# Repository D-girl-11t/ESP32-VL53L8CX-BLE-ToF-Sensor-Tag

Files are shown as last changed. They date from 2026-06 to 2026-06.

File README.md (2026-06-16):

# ESP32 BLE Time-of-Flight Sensor Tag




This project is a battery-powered BLE sensor tag built around an ESP32 and a VL53L8CX Time-of-Flight (ToF) sensor. The system continuously captures distance measurements at a fixed rate, stores recent readings in memory, and streams data over Bluetooth Low Energy whenever a client connects.

The goal of this project was to build a complete embedded system, covering hardware design, power management, real-time firmware, BLE communication, and data buffering.

---

## What It Does

* Measures distance using the VL53L8CX ToF sensor
* Samples data at a fixed rate (20 Hz by default)
* Stores the most recent measurements in a ring buffer
* Streams live or buffered data over BLE
* Continues sampling even when BLE is disconnected
* Supports battery-powered operation with USB charging
* Places the sensor into a low-power state when sampling is disabled

---

## Hardware Overview

The hardware is based on an ESP32-C3 module connected to a VL53L8CX ToF sensor over I²C.

Power comes from either:

* A single-cell LiPo battery
* USB power during charging

A BQ-series charger with power-path management handles charging and automatically switches between USB and battery operation.

For debugging and bring-up, the board includes:

* Programming header
* Test points for VBAT, VSYS, 3V3, and GND
* Charger status monitoring points
* Clearly labeled silkscreen

### Sensor Interface

The VL53L8CX is connected over I²C and uses two additional GPIO signals:

* **INT** – Sensor interrupt output
* **LPn** – Sensor enable/low-power control

The LPn pin is used to enable or disable the sensor from firmware:

* LPn HIGH → Sensor active
* LPn LOW → Sensor in low-power mode

---

## Firmware Overview

To keep sensor acquisition independent from communication, the application is split into two tasks:

### Sensor Task

Responsible for:

* Reading data from the VL53L8CX
* Maintaining a fixed sampling rate
* Writing measurements into the ring buffer
* Tracking buffer overflows

### BLE Task

Responsible for:

* BLE advertising and connections
* Sending notifications
* Handling control commands
* Streaming buffered data

Since both tasks access the same buffer, a FreeRTOS mutex is used to protect shared data.

---

## Sampling Strategy

The default sampling rate is 20 Hz, which corresponds to one measurement every 50 ms.

The sampling task runs on a fixed schedule and is intentionally kept independent of BLE activity. This ensures that sensor timing remains consistent even when notifications are being transmitted.

One practical optimization is minimizing debug print statements. Excessive UART logging can introduce delays that affect timing accuracy, especially when working with millisecond-level scheduling.

If a sensor read ever takes longer than the allocated sampling window, that sample is dropped rather than delaying future measurements. Under normal operating conditions, this is not expected to occur with the selected VL53L8CX configuration.

---

## Ring Buffer Design

The assignment required storing the last **N seconds** of sensor data.

By default:

* Sampling rate = 20 Hz
* N = 10 seconds

This results in:

* 20 samples per second
* 200 samples stored in memory

For an 8×8 VL53L8CX ranging frame:

* 64 distance values per sample
* 4 bytes per value
* 256 bytes per frame

Memory usage is approximately:

* 5 KB per second of buffered data
* 50 KB for a 10-second history

The values of **N** and buffer size are currently fixed constants for simplicity but can easily be made configurable.

### Buffer Overflow Behavior

When the buffer becomes full, the oldest data is overwritten.

For this application, retaining the most recent measurements is more useful than preserving older data, so overwrite-on-full was chosen intentionally.

Different applications may require different strategies depending on how critical the data is.

---

## BLE Control Interface

The BLE service exposes two characteristics:

### Data Characteristic

Used for notifications.

When connected, the client receives:

* Live sensor data
* Previously buffered data

### Control Characteristic

Used for configuration and runtime control.

Supported commands:

* `startSampling`
* `stopSampling`
* `startBLE`
* `stopBLE`
* `SetRate:<value>`
* `Clear`

---

## Why Separate Sampling and BLE?

The original assignment mentioned Start and Stop commands, but it was unclear whether those commands should affect the sensor, BLE communication, or both.

To make the behavior explicit, the implementation separates them into two independent controls.

### Sampling Control

* `startSampling`
* `stopSampling`

These commands control whether the sensor is actively acquiring measurements.

### BLE Control

* `startBLE`
* `stopBLE`

These commands control whether data is transmitted to connected BLE clients.

This approach makes system behavior easier to understand and provides more flexibility during testing.

---

## Operating Modes

### Sampling Enabled, BLE Disabled

The sensor continues collecting measurements and storing them in the ring buffer.

If the buffer fills up, the oldest entries are overwritten.

### Sampling Disabled

The sensor is disabled through the LPn pin and enters a low-power state.

### Sampling Enabled, BLE Enabled

The system continues collecting measurements while simultaneously transmitting data over BLE.

When BLE is enabled, buffered measurements are sent first before transitioning to live streaming.

### BLE Disabled During Operation

Sensor acquisition continues normally, but measurements are only stored locally.

### Clear Command

Removes all buffered measurements and resets buffer tracking information.

---

## Power Management

The VL53L8CX supports a low-power mode through the LPn pin, which is used whenever sampling is stopped.

ESP32 light sleep and deep sleep were also evaluated. However, entering sleep causes BLE connections to disconnect, so sleep modes are only practical when both sensor acquisition and BLE communication are inactive.

Because of this, the system remains awake whenever BLE functionality is required.

---

## Testing

BLE functionality was tested using nRF Connect.




The following scenarios were verified:

# Sampling with BLE disabled



# StopSampling and no BLE



# Sampling with BLE enabled




# Stopping and restarting sensor acquisition


# BufferSAMPLING RATE 


# Clearing buffered data



The observed behavior matched the intended design in all test cases.

---

## References

VL53L8CX Driver Library:

[https://github.com/stm32duino/VL53L8CX](https://github.com/stm32duino/VL53L8CX)

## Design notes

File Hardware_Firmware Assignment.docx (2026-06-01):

Dhana Laxmi Sirigireddy | Design of ESP32 + VL53L8CX BLE sensor system

Assignment

Design a small ESP32 + ToF BLE sensor tag where:

System

- MCU: ESP32 (ESP32-C3 or ESP32-S3 module)
- Sensor: VL53L8CX ToF over I2C (LPn + INT connected to GPIO)
- Power: 1-cell LiPo + BQ-series charger with power-path
- Comms: BLE (stream when connected, buffer when not)

Hardware task (PCB in KiCad/Altium)

- LiPo JST + USB input for charging
- BQ charger configured (charge current/termination) + documented USB vs battery behavior
- 3.3V rail sized for ESP32 peaks, proper decoupling
- ToF I2C integration (pullups/level shifting if needed), clean routing
- Bring-up features: test points (VBAT/VSYS/3V3/GND + charger status), programming header, clear silkscreen

Firmware task (ESP-IDF + FreeRTOS)

- Fixed-rate sampling (e.g., 20 Hz) independent of BLE
- Ring buffer stores last N seconds; track drops/overflows
- BLE GATT service:
  - Notify “Data” characteristic
  - Write “Control” characteristic (start/stop, set rate, clear buffer)
- When BLE connects: stream latest (or buffered) data without blocking sampling
- When sampling stops: put ToF in low power via LPn (optional light sleep)

Deliverables

- PCB project + 1–2 page design note
- ESP-IDF project + README (build/flash + UUIDs + how to test in nRF Connect)

I started by picking the microcontroller for our project and went with the ESP32-C3 WROOM-02.

The C3 is a single-core chip which is great for low-power stuff and simple WiFi/BLE tasks. It runs a bit slower than the ESP32-S3, which actually helps save energy for lightweight applications like ours.

The S3, on the other hand, is dual-core and more powerful, designed for heavier workloads like AI or advanced data processing.

Since our project is mostly about basic wireless communication and keeping power consumption low, the C3 is the better fit.

I didn’t go with the C3 Mini because the WROOM-02 gives us more flash memory and easier integration for the board we’re building.

Component Selection
ESP32-C3-WROOM-02-N4 Espressif Systems - RF Receivers, Transceivers - Distributors, Price Comparison, and Datasheets | Octopart component search (https://octopart.com/part/espressif-systems/ESP32-C3-WROOM-02-N4) (from Component Search Engine )

Datasheet
https://www.mouser.in/datasheet/2/891/Espressif_Systems_04082021_ESP32_C3_WROOM_02-2295851.pdf

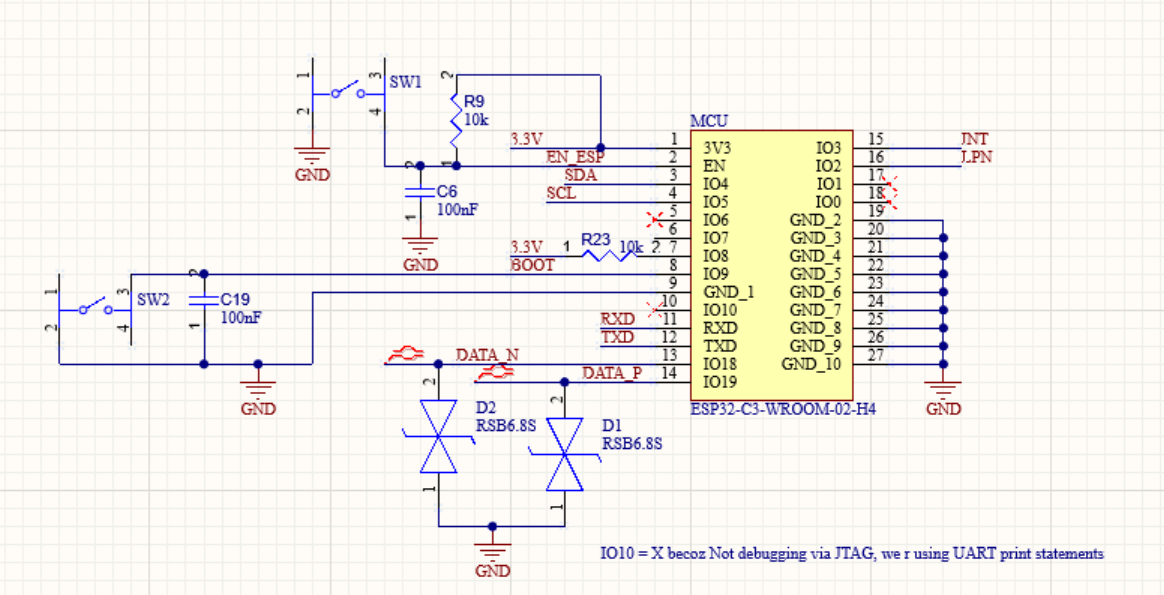
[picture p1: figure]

Next,

Sensor

I initially considered using an off-the-shelf breakout board to make things easier, but I decided to design the whole circuit myself. It turned out to be simpler given the power management path I wanted to implement.

Useful sources
BREAK OUT BOARD SCHEMATIC LINK POLOLU (https://cdn.robotshop.com/media/P/Pol/RB-Pol-1059/pdf/pololu-vl53l8cx-time-of-flight-distance-sensor-8x8-zone-4-m-range-schematics.pdf)

Datasheet
https://www.st.com/resource/en/datasheet/vl53l8cx.pdf

The power-up sequence is detailed on page 11 of the datasheet.
The sensor is connected to ESP via I2C protocol.



To communicate with the ESP, I needed a level shifter because the ESP’s GPIOs are 3.3 V while the sensor pins are 1.8 V. I chose the TXS0108ERGYR (https://www.ti.com/lit/ds/symlink/txs0108e.pdf?ts=1769859893600)for this purpose.
I followed the typical application circuit on page 19 of the datasheet.

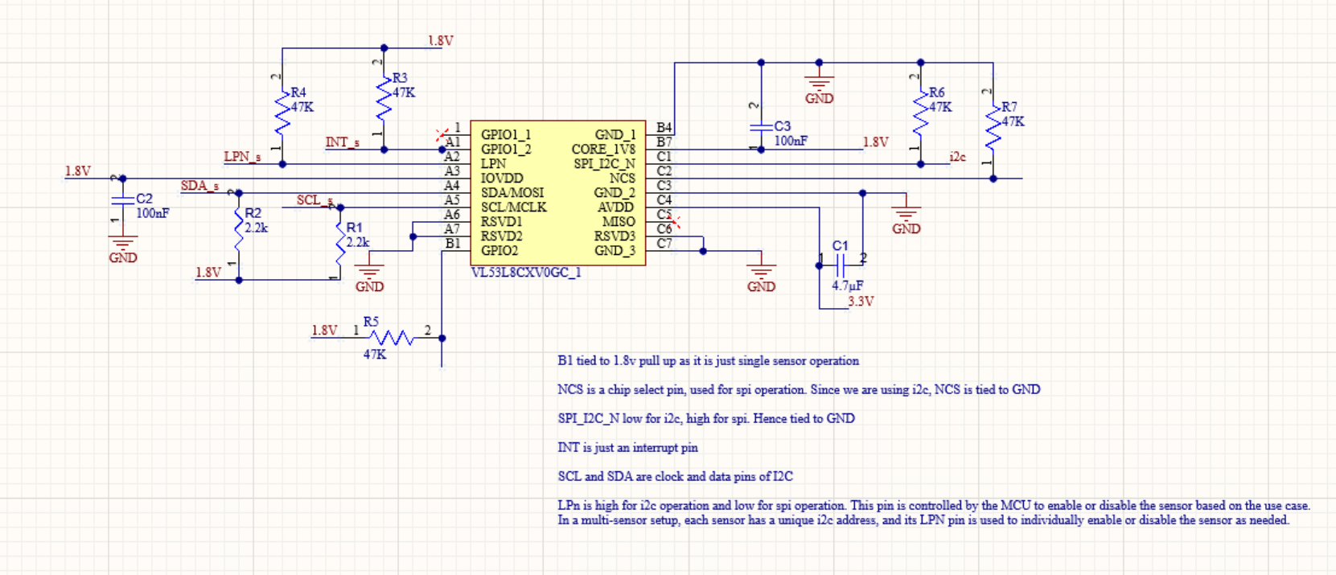
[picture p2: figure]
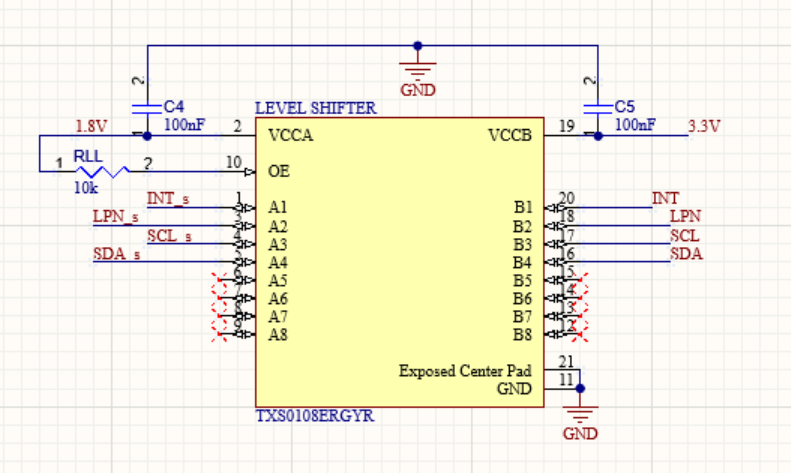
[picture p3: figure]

Flashing and Debugging the ESP32-C3 Board

IO9 is the boot pin on this module.

The ESP32-C3 WROOM-02 has a built-in USB peripheral, which theoretically allows flashing via USB directly by connecting the USB-C data lines to IO18 (D+) and IO19 (D−).

However, this method is not as straightforward as using a standard USB-to-UART bridge.

To make development simple, I implemented a USB-to-UART bridge using the CP2102. This setup:

- Automatically handles boot/reset toggling
- Provides USB debugging, allowing UART print statements to be read directly via USB-C
- Works with standard tools like esptool.py for firmware flashing

For minimal hardware, the board can be flashed manually using the exposed UART pins (TXD, RXD, VCC, GND) along with the BOOT and EN buttons:

1. Hold BOOT (IO9) LOW
2. Press and release EN (RESET)
3. Release BOOT
4. Run

I haven’t used the JTAG feature; those pins are repurposed for I2C, and anyway UART debugging covers all necessary testing and log output.

According to the official ESP-IDF documentation, ESP32 boards typically use a USB-to-UART bridge to expose a virtual COM port for flashing. If auto-download isn’t available, holding BOOT while resetting the board manually enters flash mode. This matches my setup: the CP2102 bridge handles auto-boot, enables convenient UART debugging, and supports standard flashing tools, making development and testing much easier. (ESP-IDF Docs (https://docs.espressif.com/projects/esp-idf/en/stable/esp32/get-started/establish-serial-connection.html))

Schematic source help - https://dl.espressif.com/dl/schematics/SCH_ESP32-C3-DEVKITC-02_V1_1_20210126A.pdf

Powerpath

The board is powered using either a LiPo battery connected via a JST connector or USB-C.

The BQ24072 battery charger IC manages power flow between these sources and the system. (BQ24072 Datasheet (https://www.ti.com/lit/ds/symlink/bq24072t.pdf?ts=1769850111450)). Page 29 has a useful application schematic.

VBUS (USB-C input) When USB-C is connected, it provides power to the BQ24072, which charges the LiPo battery and supplies the system.

VBAT (Battery) Represents the LiPo battery voltage. The battery powers the system whenever USB-C is disconnected or the charger allows.

VSYS (System output from BQ24072) The charger IC outputs VSYS, which automatically selects the higher-priority power source (USB or battery) to provide a stable system voltage.

LDO → 3.3 V rail VSYS is fed into a low-dropout regulator (LDO) to generate a clean 3.3 V supply for the ESP32-C3 and peripherals.


Differential pair impedance
1. Change the rules in diff routine
2. Create impedance profile in layer stack manager
3. Apply in rules

—--

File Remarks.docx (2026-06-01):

Remarks

1. Removing print statement, can save time and makes sure the cycle doesnt break. Since we are dealing with ms [improvement could be done]
2. Sleep mode is disconnecting BLE (both light and deep). Sleep used only when both BLE not asking and sensor not sending
3. Mutex is used to safeguard buffer [FREERTOS] 2 TASKS - SensorTask, BLETask

4. N is default 10, can be changed later
5. And so is buffer size
6. LPN pin operates as per sensor needed to work or not , if yes HIGH, no then low
7. STOP and START are not clear in the assignment, So I used startSampling and stopSampling for sensor to work or not and startBLE and stopBLE for bluetooth to send data or not
8. When startBLE starts, ring buffer values will be sent and buffer slowly empties
9. If Buffer overfilled, overwrites old data as the data here is not critical. Different use case different methods
10. I havent changed the buffer size when the sampling rate changes. I put constant for simplicity

sYSTEM ALSO DEPENDS ON PREVIOUS STATE
Control
1. startSampling
2. stopSampling
3. startBLE
4. stopBLE
5. Setrate:10

6. Clear

For the sensor -
For this assignment lets just do 1 capture per every 50ms. (given fixed sampling rate is 20Hz)

If it takes more than 50ms, lets drop. (it wont usually wont according to the settings or configurations we choose. But if ToF is greater than yeah )

Okay, according to assignment, ring buffer stores last N seconds

1 second = 1000ms = 50 * 20 ms = 50ms * 20 = 20 Samples per second ( if we capture one data value per every 50ms)

Buffer size for N seconds = 20N

8×8 array = 64 values

Each value = 4 bytes = 64 × 4 = 256 bytes per sample

20 samples per second = 256 × 20 = 5120 bytes ( approx 5 KB per second)

For N seconds: Buffer size = 256 × 20 × N = 5120 × N bytes

To read from sensor, use this github page to get real time values from sensor,
https://github.com/stm32duino/VL53L8CX

11. Using nrfConnect, below are the attached pictures

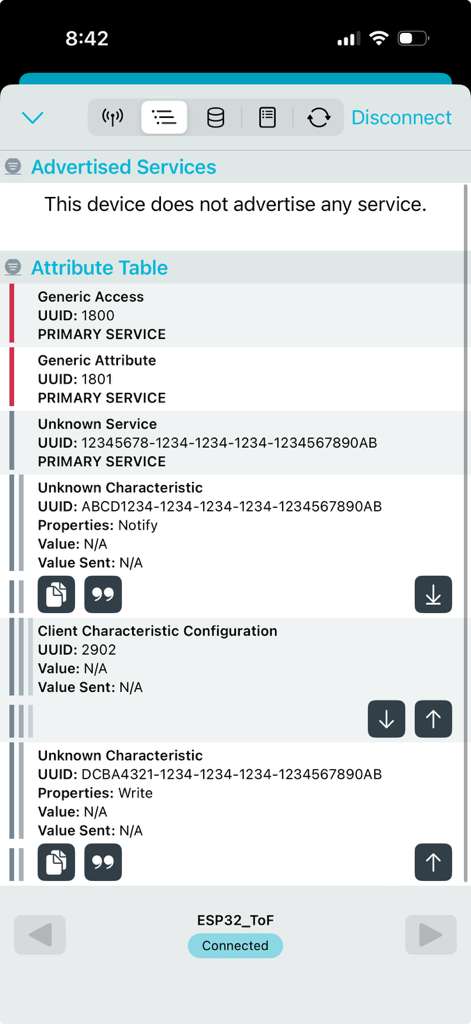
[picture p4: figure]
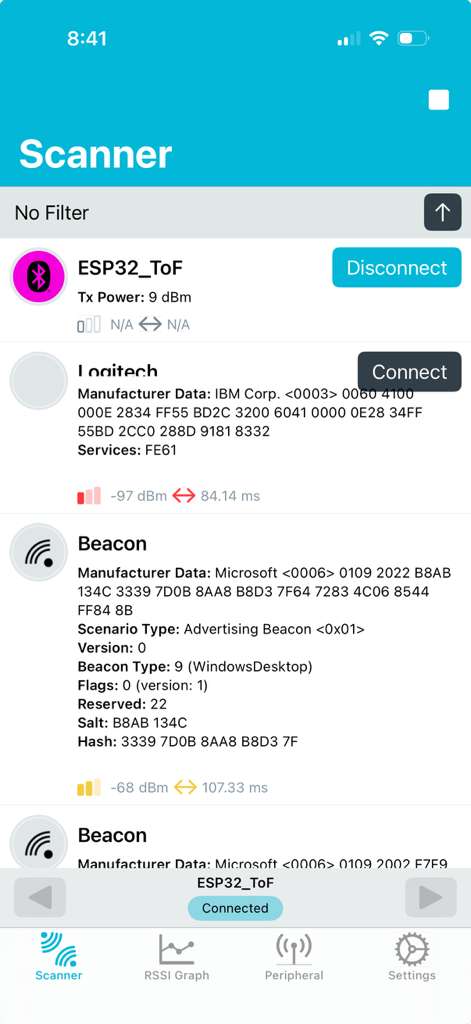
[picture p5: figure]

Normal startSampling = 1 and NO ble . JUST READ AND STORE . OVERFILL -> OVERWRITE

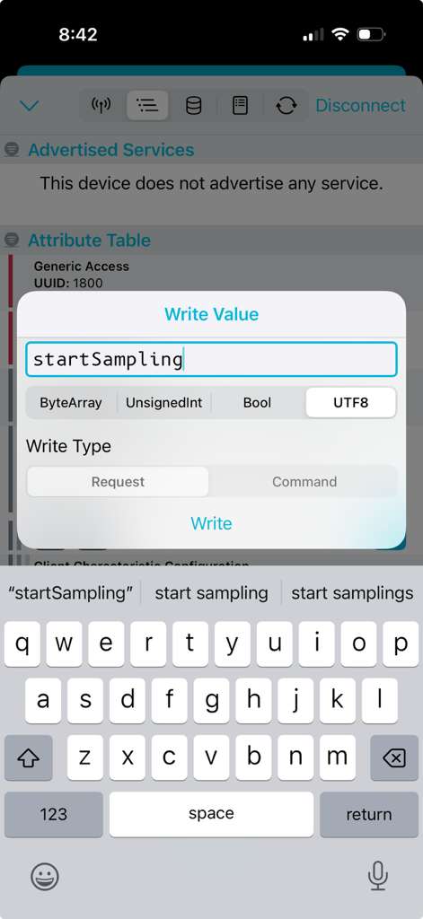
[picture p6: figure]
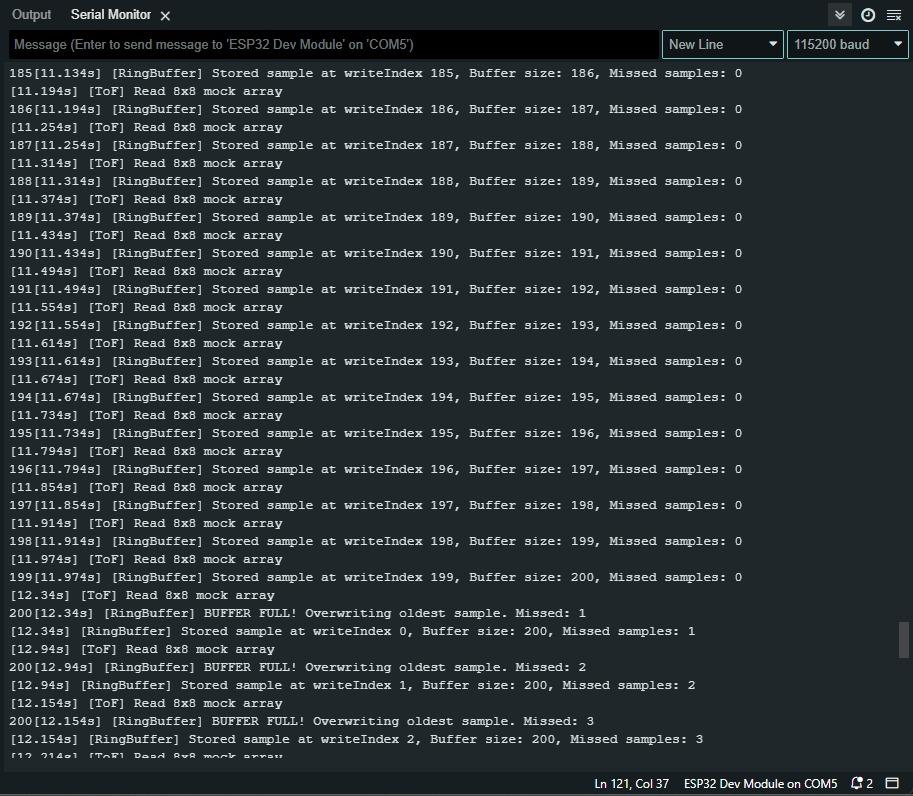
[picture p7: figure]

stopSampling and no BLE

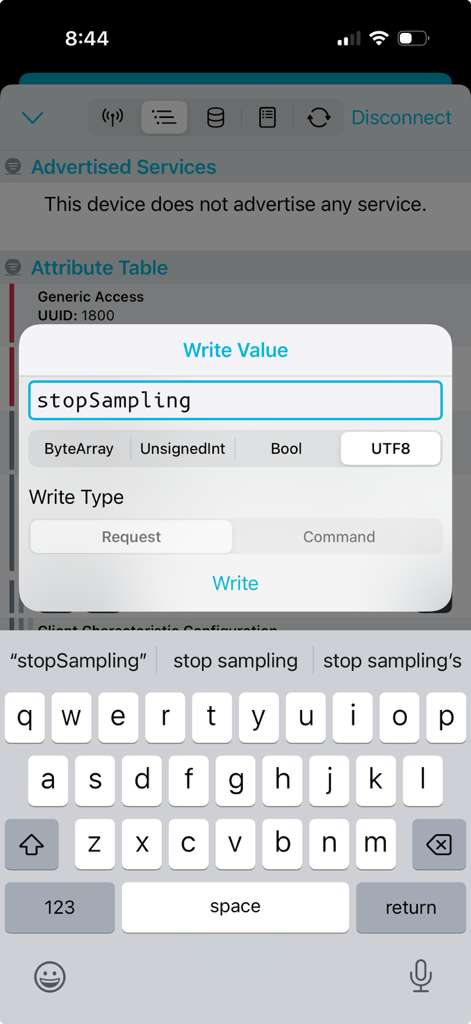
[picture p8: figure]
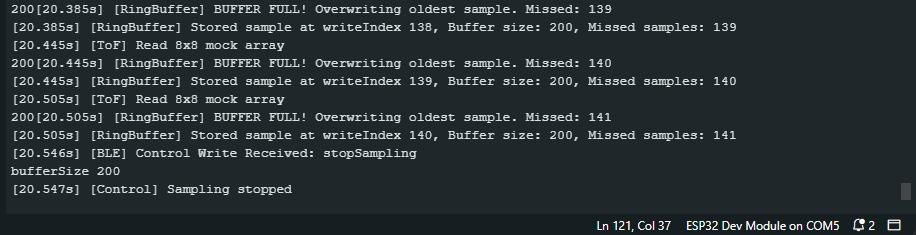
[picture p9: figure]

startBLE AND startSampling

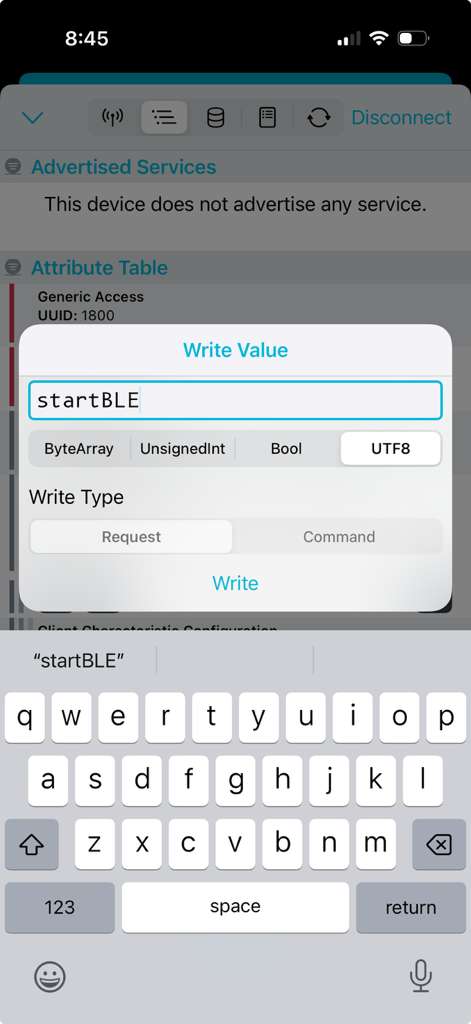
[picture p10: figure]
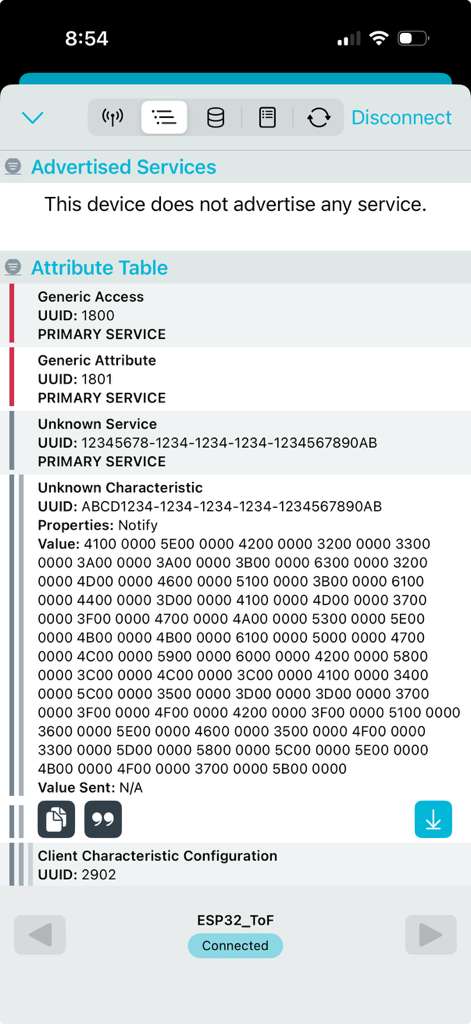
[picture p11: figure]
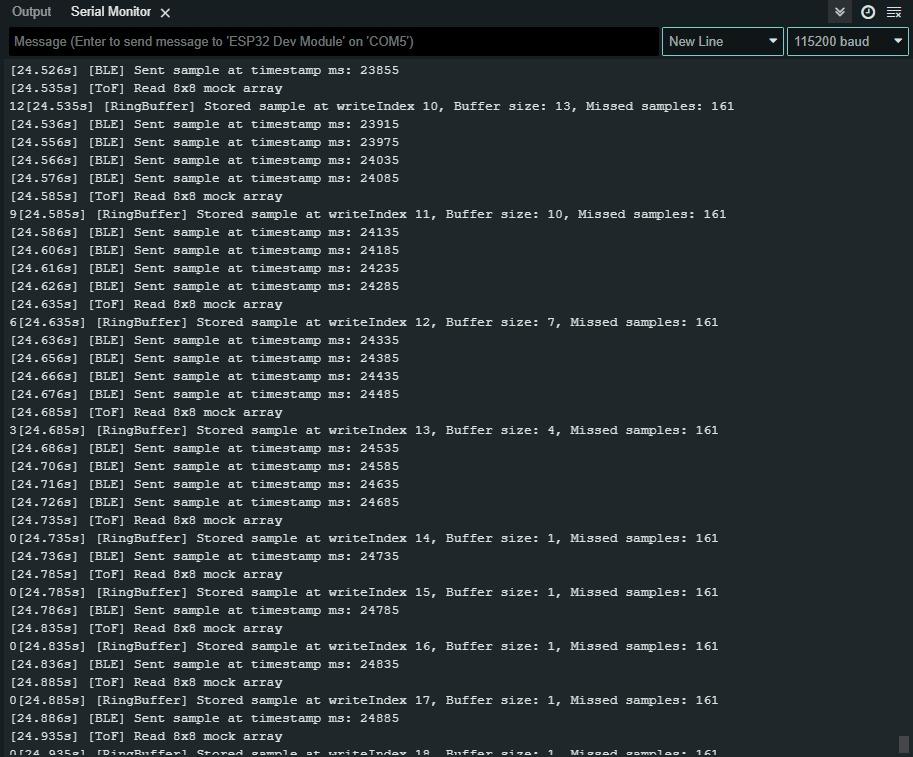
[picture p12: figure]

stopBLE. Back to normal

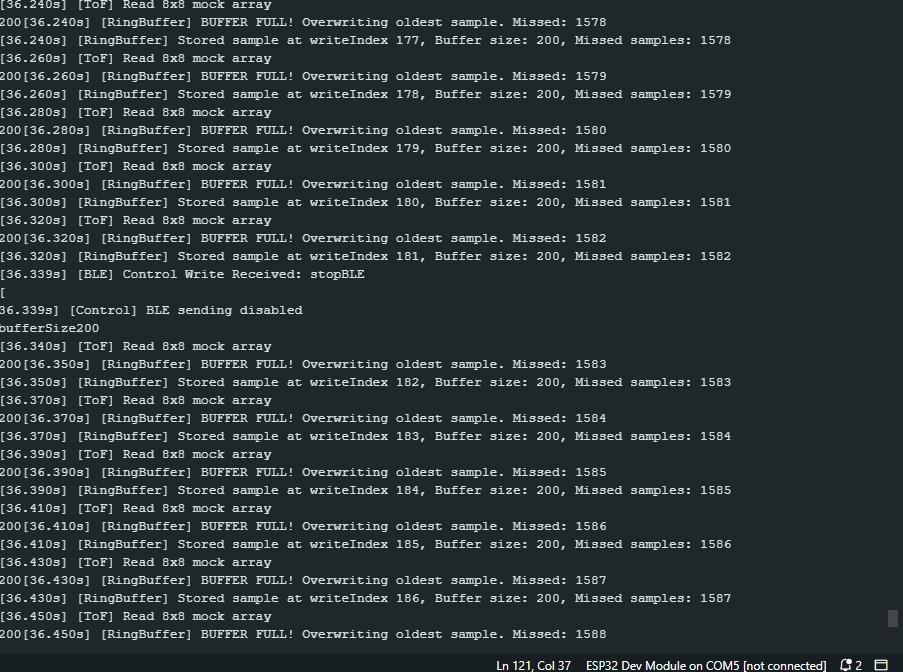
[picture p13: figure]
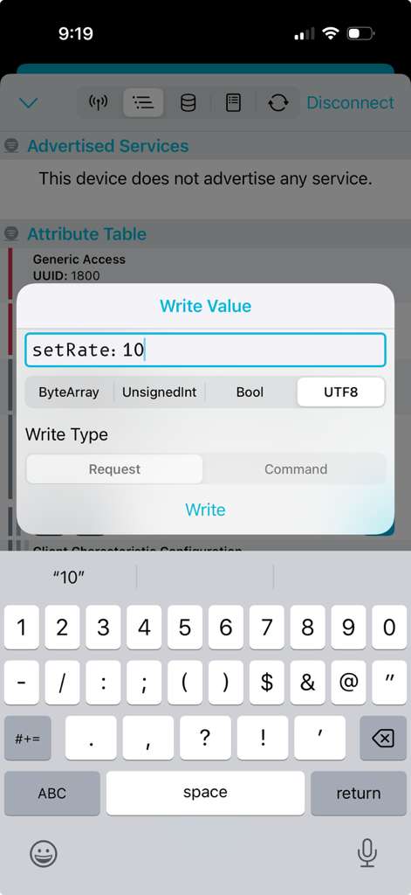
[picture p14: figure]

Clear

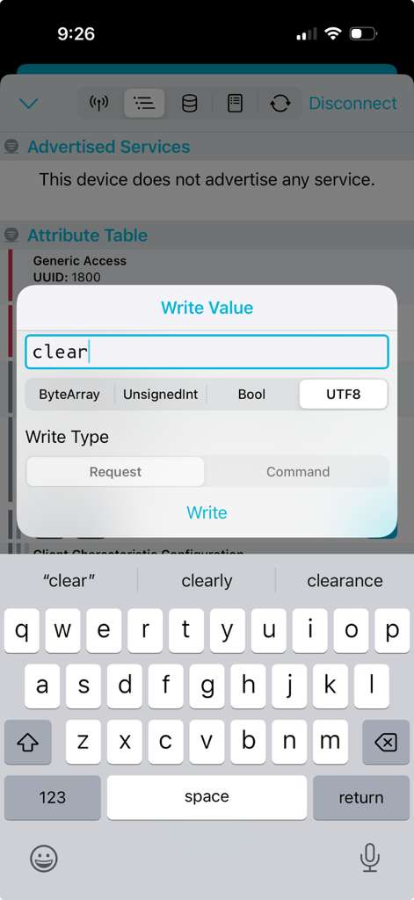
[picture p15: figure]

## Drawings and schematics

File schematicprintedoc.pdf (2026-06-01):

# Power

# ESP32

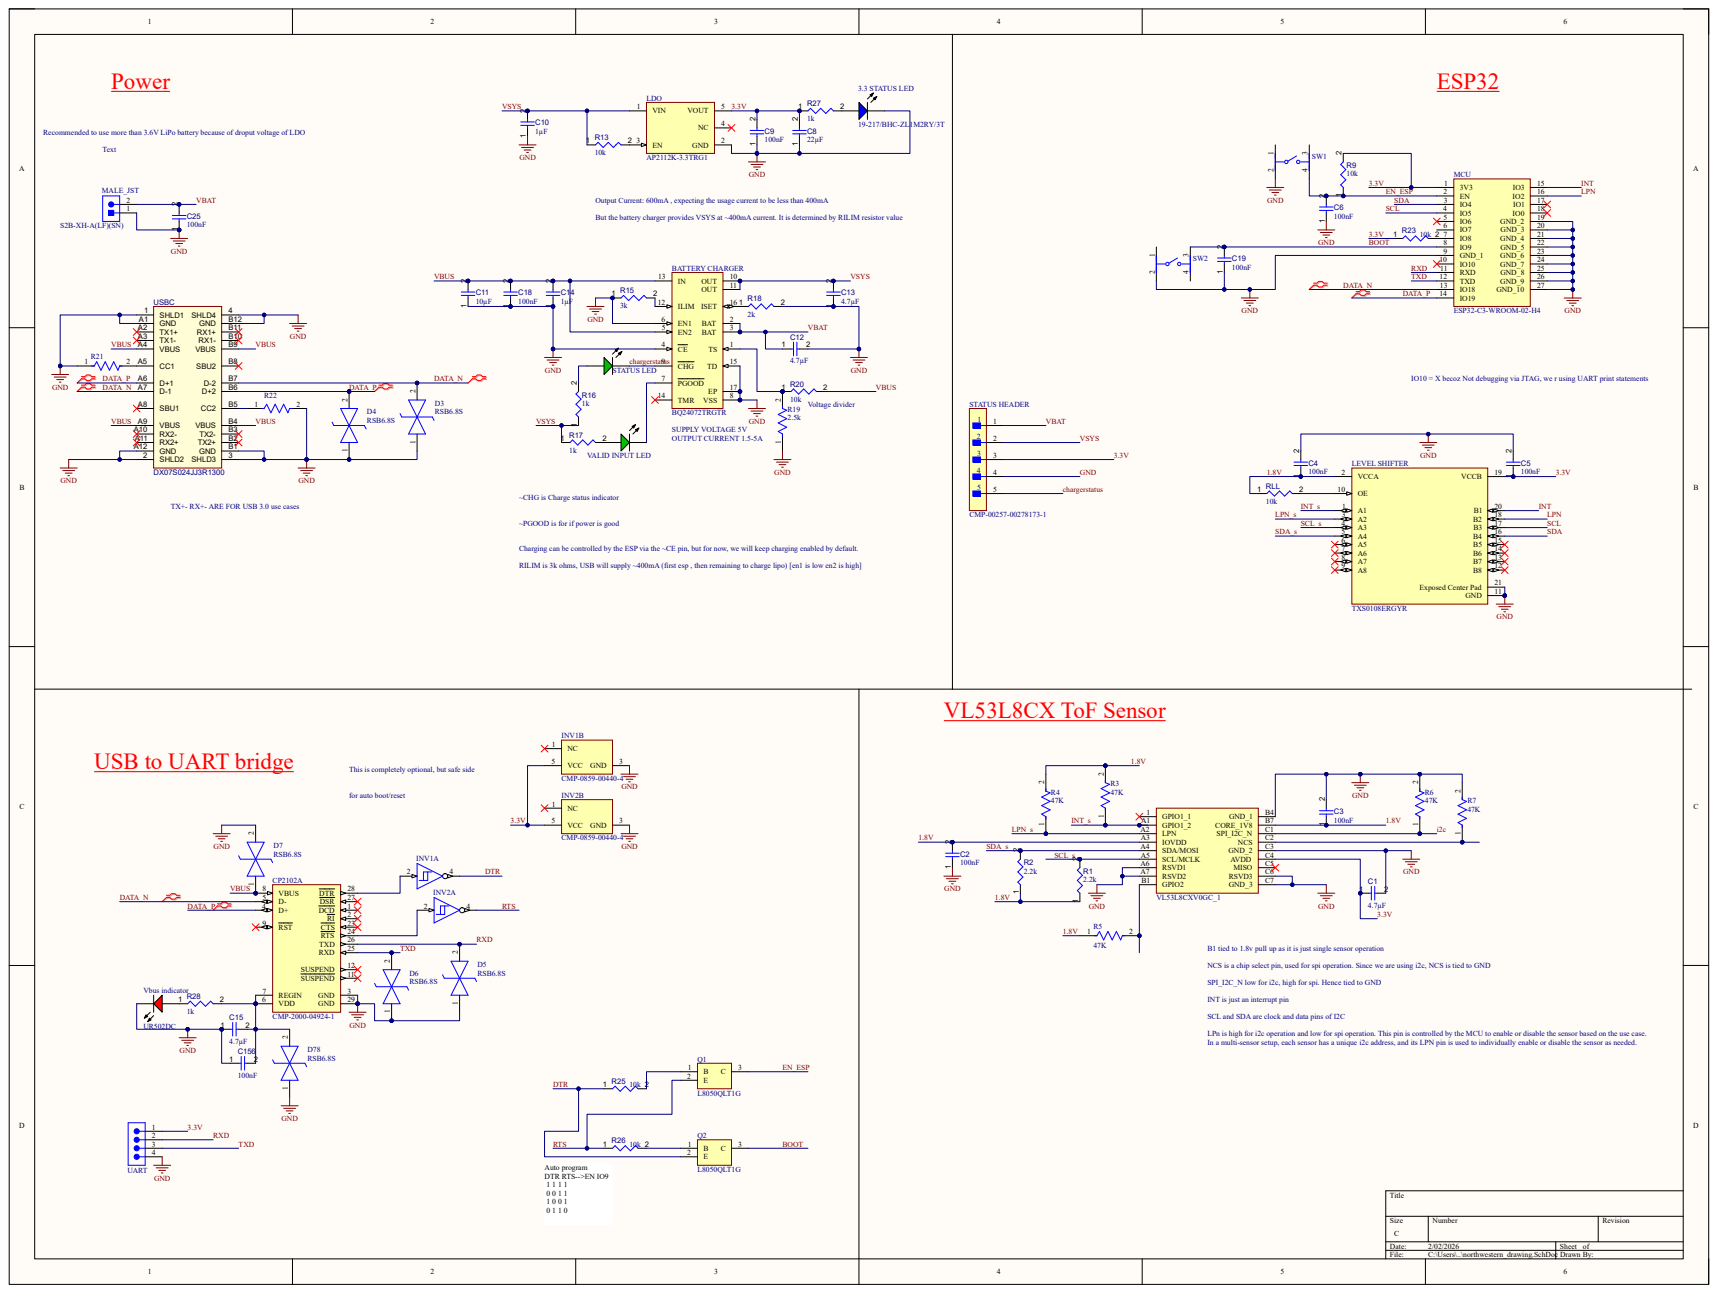
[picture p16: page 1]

Recommended to use more than 3.6V LiPo battery because of droput voltage of LDO

Output Current: 600mA , expecting the usage current to be less than 400mA

But the battery charger provides VSYS at ~400mA current. It is determined by RILIM resistor value

IO10 = X becoz Not debugging via JTAG, we r using UART print statements

~CHG is Charge status indicator

TX+- RX+- ARE FOR USB 3.0 use cases

~PGOOD is for if power is good

Charging can be controlled by the ESP via the ~CE pin, but for now, we will keep charging enabled by default.

RILIM is 3k ohms, USB will supply ~400mA (first esp , then remaining to charge lipo) [en1 is low en2 is high]

for auto boot/reset

B1 tied to 1.8v pull up as it is just single sensor operation

NCS is a chip select pin, used for spi operation. Since we are using i2c, NCS is tied to GND

SPI_I2C_N low for i2c, high for spi. Hence tied to GND

INT is just an interrupt pin

SCL and SDA are clock and data pins of I2C

LPn is high for i2c operation and low for spi operation. This pin is controlled by the MCU to enable or disable the sensor based on the use case.
In a multi-sensor setup, each sensor has a unique i2c address, and its LPN pin is used to individually enable or disable the sensor as needed.

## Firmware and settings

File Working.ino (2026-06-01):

#include <Arduino.h>
#include <BLEDevice.h>
#include <BLEServer.h>
#include <BLEUtils.h>
#include <BLE2902.h>
#include <freertos/semphr.h>
#include "esp_sleep.h" // For light sleep

// -------------------- UUIDs --------------------
#define SERVICE_UUID        "12345678-1234-1234-1234-1234567890ab"
#define DATA_CHAR_UUID      "abcd1234-1234-1234-1234-1234567890ab"
#define CONTROL_CHAR_UUID   "dcba4321-1234-1234-1234-1234567890ab"

// -------------------- Globals --------------------
BLEServer* pServer;
BLECharacteristic* pDataChar;
BLECharacteristic* pControlChar;

bool sampling = true;         // Sensor acquisition flag
bool bleSendEnabled = false;    // BLE notification flag
bool deviceConnected = false;  // BLE connection state

#define WIDTH 8
#define HEIGHT 8
#define SAMPLE_SIZE (WIDTH*HEIGHT*4) // 8x8 array, 4 bytes per value = 256 bytes
#define BUFFER_SECONDS 10             // Buffer stores last N seconds
#define LPN_PIN 15                     // Example LNT / LPn pin

uint16_t effectiveRate = 20; // Samples per second, adjustable via BLE

// Ring buffer parameters
#define MAX_RING_SAMPLES 200  // max slots (can be bigger for large N)
struct RingSample {
    int64_t timestamp_ms;          // Timestamp in ms
    uint8_t data[SAMPLE_SIZE];     // 8x8 ToF data
};
RingSample ringBuffer[MAX_RING_SAMPLES];

uint16_t writeIndex = 0;
uint16_t readIndex  = 0;
uint16_t bufferSize = 0;
uint32_t missedSamples = 0;

SemaphoreHandle_t ringMutex; // Mutex to protect ring buffer

// -------------------- Helper: timestamp string --------------------
String ts() {
    uint32_t t = millis();
    uint32_t s = t / 1000;
    uint32_t ms = t % 1000;
    return String(s) + "." + String(ms) + "s";
}

// -------------------- Mock ToF Reading --------------------
void getToFArray(uint32_t *array) {
    for (int i = 0; i < WIDTH*HEIGHT; i++) {
        array[i] = random(50, 100); // Mock 50-100
    }
    Serial.print("["); Serial.print(ts()); Serial.println("] [ToF] Read 8x8 mock array");
}

// -------------------- BLE Server Callbacks --------------------
class MyServerCallbacks : public BLEServerCallbacks {
    void onConnect(BLEServer* pServer) override {
        deviceConnected = true;
        Serial.print("["); Serial.print(ts()); Serial.println("] [BLE] Device connected!");
    }
    void onDisconnect(BLEServer* pServer) override {
        deviceConnected = false;
        Serial.print("["); Serial.print(ts()); Serial.println("] [BLE] Device disconnected!");
        pServer->getAdvertising()->start(); // Restart advertising
        Serial.print("["); Serial.print(ts()); Serial.println("] [BLE] Restarted advertising...");
    }
};

// -------------------- BLE Control Callbacks --------------------
class ControlCallbacks : public BLECharacteristicCallbacks {
    void onWrite(BLECharacteristic* pChar) override {
        String value = pChar->getValue();
        Serial.print("["); Serial.print(ts()); Serial.print("] [BLE] Control Write Received: "); 
        Serial.println(value);

        // --- Start/Stop Sampling ---
        if (value == "startSampling") {
            sampling = true;
            Serial.print("bufferSize");
            Serial.print(bufferSize);
            Serial.print("["); Serial.print(ts()); Serial.println("] [Control] Sampling started");
        } 
        else if (value == "stopSampling") {
            sampling = false;
            Serial.print("bufferSize ");
            Serial.println(bufferSize);
            Serial.print("["); Serial.print(ts()); Serial.println("] [Control] Sampling stopped");
        }

        // --- Start/Stop BLE notifications ---
        else if (value == "startBLE") {
            bleSendEnabled = true;
            Serial.print("bufferSize");
            Serial.println(bufferSize);
            Serial.print("["); Serial.print(ts()); Serial.println("] [Control] BLE sending enabled");
        } 
        else if (value == "stopBLE") {
            bleSendEnabled = false;
            Serial.println("["); Serial.print(ts()); Serial.println("] [Control] BLE sending disabled");
            Serial.print("bufferSize");
            Serial.println(bufferSize);
        }
        // --- Set sample rate ---
        else if (value.startsWith("setRate:")) {
            int newRate = value.substring(8).toInt(); // get number after 'setRate:'
            if (newRate > 0 && newRate <= 1000) {
                effectiveRate = newRate; // Change FreeRTOS task rate dynamically
                Serial.print("["); Serial.print(ts()); Serial.print("] [Control] Sample rate set to ");
                Serial.println(effectiveRate);
            }
        }

        // --- Clear ring buffer ---
        else if (value == "clear") {
            if (xSemaphoreTake(ringMutex, portMAX_DELAY) == pdTRUE) {
                writeIndex = 0; readIndex = 0; bufferSize = 0; missedSamples = 0;
                xSemaphoreGive(ringMutex);
                Serial.print("["); Serial.print(ts()); Serial.println("] [Control] Ring buffer cleared");
            }
        }
    }
};

// -------------------- Setup BLE --------------------
void setupBLE() {
    Serial.print("["); Serial.print(ts()); Serial.println("] [BLE] Initializing BLE...");
    BLEDevice::init("ESP32_ToF");
    pServer = BLEDevice::createServer();
    pServer->setCallbacks(new MyServerCallbacks());

    BLEService *pService = pServer->createService(SERVICE_UUID);

    // Data characteristic (Notify)
    pDataChar = pService->createCharacteristic(DATA_CHAR_UUID, BLECharacteristic::PROPERTY_NOTIFY);
    pDataChar->addDescriptor(new BLE2902());
    Serial.print("["); Serial.print(ts()); Serial.println("] [BLE] Data characteristic created");

    // Control characteristic (Write)
    pControlChar = pService->createCharacteristic(CONTROL_CHAR_UUID, BLECharacteristic::PROPERTY_WRITE);
    pControlChar->setCallbacks(new ControlCallbacks());
    Serial.print("["); Serial.print(ts()); Serial.println("] [BLE] Control characteristic created");

    pService->start();
    pServer->getAdvertising()->start();
    Serial.print("["); Serial.print(ts()); Serial.println("] [BLE] BLE Advertising started...");
}

// -------------------- Task 1: Sensor acquisition --------------------
void SensorTask(void* parameter) {
    Serial.print("["); Serial.print(ts()); Serial.println("] [Task] SensorTask started");

    uint32_t tofArray[WIDTH*HEIGHT];

    while(true) {
        // Low-power mode if sampling stopped
        if (!sampling) {
            digitalWrite(LPN_PIN, LOW); // HIGH = ACTIVE
            vTaskDelay(pdMS_TO_TICKS(100));
            continue;
            if(!bleSendEnabled) {
              esp_light_sleep_start();
            }
        } 
        else {
            digitalWrite(LPN_PIN, HIGH); // sleep mode
        }

        // --- Read ToF data ---
        getToFArray(tofArray);
        Serial.print(bufferSize);

        // --- Store in ring buffer ---
        if (xSemaphoreTake(ringMutex, portMAX_DELAY) == pdTRUE) {

            // Buffer full -> overwrite oldest sample
            if (bufferSize == MAX_RING_SAMPLES) {
                missedSamples++;
                readIndex = (readIndex + 1) % MAX_RING_SAMPLES;
                bufferSize--;
                Serial.print("["); Serial.print(ts()); Serial.print("] [RingBuffer] BUFFER FULL! Overwriting oldest sample. Missed: ");
                Serial.println(missedSamples);
            }

            ringBuffer[writeIndex].timestamp_ms = millis();
            memcpy(ringBuffer[writeIndex].data, tofArray, SAMPLE_SIZE);

            Serial.print("["); Serial.print(ts()); Serial.print("] [RingBuffer] Stored sample at writeIndex ");
            Serial.print(writeIndex);
            bufferSize++;
            Serial.print(", Buffer size: "); Serial.print(bufferSize);
            Serial.print(", Missed samples: "); Serial.println(missedSamples);

            writeIndex = (writeIndex + 1) % MAX_RING_SAMPLES;
            xSemaphoreGive(ringMutex);
        }

        // Delay according to effectiveRate
        vTaskDelay(pdMS_TO_TICKS(10));
    }
}

// -------------------- Task 2: BLE Notifications --------------------
void BLETask(void* parameter) {
    Serial.print("["); Serial.print(ts()); Serial.println("] [Task] BLETask started");

    while(true) {
        if (deviceConnected && bleSendEnabled) {
            uint8_t data[SAMPLE_SIZE];
            int64_t timestamp = 0;

            if (xSemaphoreTake(ringMutex, portMAX_DELAY) == pdTRUE) {
                if (bufferSize > 0) {
                    // Get oldest sample
                    memcpy(data, ringBuffer[readIndex].data, SAMPLE_SIZE);
                    timestamp = ringBuffer[readIndex].timestamp_ms;

                    readIndex = (readIndex + 1) % MAX_RING_SAMPLES;
                    bufferSize--;
                } else {
                    xSemaphoreGive(ringMutex);
                    vTaskDelay(pdMS_TO_TICKS(1));
                    continue;
                }
                xSemaphoreGive(ringMutex);
            }

            // Notify BLE
            pDataChar->setValue(data, SAMPLE_SIZE);
            pDataChar->notify();
            Serial.print("["); Serial.print(ts()); Serial.print("] [BLE] Sent sample at timestamp ms: ");
            Serial.println(timestamp);
        }

        vTaskDelay(pdMS_TO_TICKS(10));
    }
}

// -------------------- Setup --------------------
void setup() {
    Serial.begin(115200);
    delay(1000);

    pinMode(LPN_PIN, OUTPUT);

    // Create mutex
    ringMutex = xSemaphoreCreateMutex();
    if (ringMutex == NULL) {
        Serial.println("[Error] Failed to create ring buffer mutex!");
        while(1);
    }

    setupBLE();

    // Create FreeRTOS tasks
    xTaskCreatePinnedToCore(SensorTask, "SensorTask", 8192, NULL, 1, NULL, 1);
    xTaskCreatePinnedToCore(BLETask, "BLETask", 8192, NULL, 1, NULL, 1);

    Serial.print("["); Serial.print(ts()); Serial.println("] [Setup] FreeRTOS tasks created");
}

// -------------------- Loop --------------------
void loop() {
    // Nothing; tasks handle everything
    vTaskDelay(pdMS_TO_TICKS(1000));
}
